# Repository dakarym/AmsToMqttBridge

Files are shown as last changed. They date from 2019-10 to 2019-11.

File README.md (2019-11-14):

# AMS <-> MQTT Bridge
 This project may help you build your own reader for HAN data streamed from the new AMS electrical meters installed in Norway in 2017/2018. Data is read using an Arduino-programmed ESP8266 (in an ESP12 module from AI Thinker), then pushed to MQTT over WiFi. You can have full control over this data, and you can basically do anything with it. 

 This project does not include any fancy UI setup or even storage for the AMS data.

 *Building this project will require some skills in ordering and assembling  electronic circuits as well as programming, and I have not included detailed instructions to take a beginner through the steps. I still hope some still find information here useful, maybe also for other projects.*

## Self powered HAN reader -- Work in progress

This is an update for a new self powered HAN [PCB](/PCB/KiCAD/HAN_SELF_POWERED) as originally conceived by ArnieO on the home automation [thread](https://www.hjemmeautomasjon.no/forums/topic/4933-lesing-av-amshan-uten-spenningsforsyning-the-complicated-way/).  Details on the hardware change is on the PCB [README](/PCB/README.md).  This version does not need a USB power connection.  Instead energy is taken from the HAN port connection and stored for use on the board.  A DC-DC buck converter based on the LTC3642 provides 3.3V at ~35ma from the 24V supply.  

The design has been tested and running successfully on an Aidon meter for the last 3 months.  Currently testing is pending on Kamstrup and Kafia style meters.

#### Open items / Limitations:
* The current that the buck can provide is limited to the maximum power supported by the meter HAN port.  The maximum value varies based on the meter type.  More information can be found [here](/Debugging/Documentation).  Currently the Aidon has the highest power available, but also has the fastest list frequency of 2.5 seconds.  Kamstrup and Kafia are at 10 second lists which may be beneficial as more time can be spent in low power idling.
* The most critical time for energy starvation is during the inital startup.  If the wifi or MQTT connection takes too long, the device will drop below the 2.65V cutoff for the voltage supervisor and will restart.  
* Due to this, the following edits in the [sketch](/Arduino Code/AmsToMqttBridge/AmsToMqttBridge.ino) were made:
  * Elimination of the 5 second waiting for AP time
  * Checking of the Vcc level at bootup and deepsleeping if insufficient voltage
  * Checking of the Vcc before entering the read message loop
* Fine tuning of the peak current trip threshold on the buck converter to balance average power draw with minimizing peak currents.
* Fine tuning of input current surge limiters for different meter types.  To be tested/verified soon.
  * Currently the design uses an NSI45020 as a 20 ma current clamp.  Below is a screenshot of the input surge with discharged input capacitors.  Yellow is the input current with 0.1V per ma scaling.  Cyan is input voltage.  Note the peak current clamped at ~27ma.
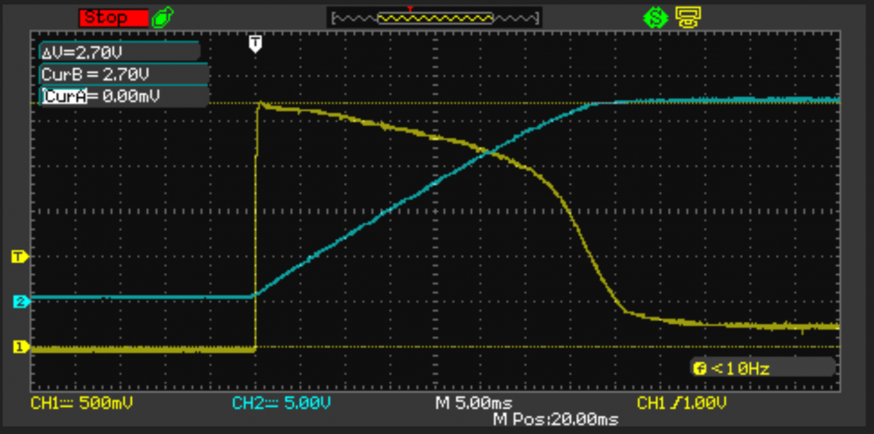
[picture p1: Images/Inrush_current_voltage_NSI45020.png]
NSI45020_Inrush

  * Alternatively an NPN current clamp could be used.  Such an example is shown below with the same measurements and scaling as above.  Note the peak current clamped at ~8.5ma.
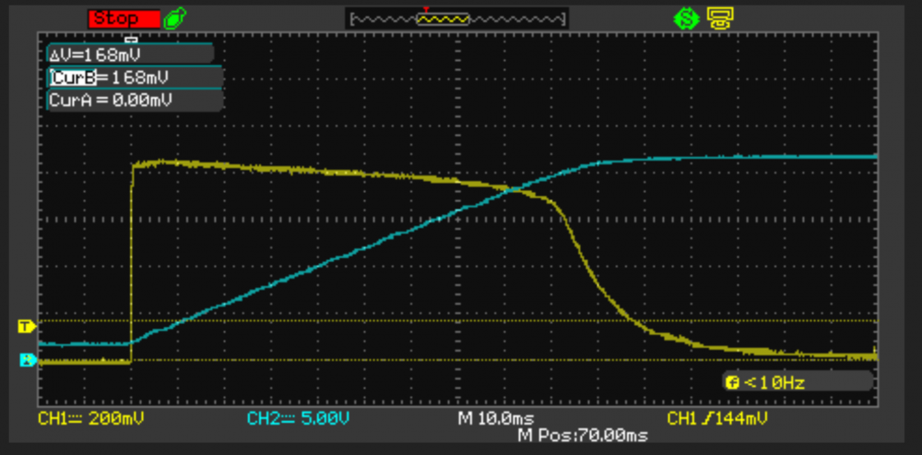
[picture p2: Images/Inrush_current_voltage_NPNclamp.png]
NPN_Inrush
  
* OTA updates will likely not be possible with this design, but will need testing
* Inital configuration of Wifi credentials and meter type will need to be done when connected to an external 3.3V supply.
* The auto reset funtionality  is implemented based on the circuit and testing of Kevin Darrah and explained [here](https://youtu.be/HdHzxM6fEig).  It is tested working on a couple of my boards with good results.

#### Next Steps:
* Test and verify on other meter types
* Respin PCB design to correct changes as needed
* Reduce cost of BOM and limited value components
* Share project on PCBWay
* Design optional case for 3d printing

## The previous hardware
The HAN Reader Hardware

*The completed board mounted in a [3D printed enclosure](/Electrical/HAN_ESP_TSS721/enclosure)*

The HAN Reader Installed

*...installed with the electrical meter...*

Data from MQTT displayed on a Node Red Dashboard

*...and, showing data on a [Node Red](https://nodered.org/) dashboard*

## Background
The purpose of this project is to collect information and build a simplified bridge for reading serial DLSM/M-bus information from electrical power meters (AMS), provided over the HAN port, and publishing to some IoT friendly target.

Components will be ESP8622, Arduino code and an M-bus <-> 3.3V serial interface

As a start, we should try to get information from the three types of AMS meters currently being installed in Norway. Some details about these are available here: [NVE_Info_kunder_HANgrensesnitt.pdf](./Debugging/Documentation/NVE_Info_kunder_HANgrensesnitt.pdf)

Quite some work was put into parse and guess how the data protocol was defined. Unfortunately, I did not have access to the (rather expensive) standardization documentation, but with some collaborative effort we solved most details.

### This project includes

- [X] [Circuit to read MBus data, parse the DSLM and report to MQTT over WiFi](./PCB/KiCAD/HAN_ESP_TSS721)
- [X] [Code to capture and analyze data from a PC](./Debugging/Code/HanDebugger)
- [X] [Code to capture and analyze data from Arduino](./Debugging/Code/ESPDebugger)
- [X] [Sample data from various meters](./Debugging/Samples)
- [X] [Documentation on HAN / MBus / DLMS/COSEM](./Debugging/Documentation)
- [X] [Code to parse DLMS data into a structure](./Arduino%20Code/Arduino%20Libraries/HanReader/src)
- [X] [Real schematics, including ESP8266](./PCB/KiCAD/HAN_ESP_TSS721#schematics)
- [X] [PCB layout](./PCB/KiCAD/HAN_ESP_TSS721#pcb)
- [X] [Component list](./PCB/KiCAD/HAN_ESP_TSS721#componenet-list)
- [X] [Arduino library](./Arduino%20Code)
- [X] [Complete Arduino sketch to read values and report to MQTT server](./Arduino%20Code/AmsToMqttBridge)

[The completed project](./Arduino%20Code/AmsToMqttBridge) also includes:

- Boot as Access Point and web server to allow config from a web browser. This allows you to set SSID, password, MQTT server and port, as well as topics for publish and subscribe
- On-board temperature sensor, also reported in json to MQTT

## Electrical design

The [most recent design](/PCB/KiCAD/HAN_ESP_TSS721) uses an [ESP8266](http://esp8266.net/) in an ESP12 module from [AI Thinker](https://www.ai-thinker.com) for micro processing and the [TSS721](http://www.ti.com/product/TSS721A) from Texas Instruments for level conversion from M-Bus to TTL (3.3V). An earlier design solved the level conversion using an op-amp, which might be an easier and more available solution, but also more error-prone. See more details in [electrical design](./Electrical).

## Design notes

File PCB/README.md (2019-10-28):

# Overview

Here are links to the different board designs together with a short summary.

## HAN_SELF_POWERED (Self contained and HAN Powered)

This [board](HAN_SELF_POWERED) contains a built in power supply to run without any external connection.  It is an evolution of the design proposed by ArnieO on the home automation forum [thread](https://www.hjemmeautomasjon.no/forums/topic/4933-lesing-av-amshan-uten-spenningsforsyning-the-complicated-way/).

Noteable changes from the below boards are:
* Uses [LTC3642](https://www.analog.com/media/en/technical-documentation/data-sheets/3642fc.pdf) for power delivery from the HAN signals
* Current limiter for preventing inrush tripping of overcurrent on HAN reader
* Voltage supervisor circuit via [TPS3808](http://www.ti.com/lit/ds/symlink/tps3808.pdf) for controlled ESP startup
* New layout with surface mount components and reduced size

Building notes:
* JP2 must be closed to enable recovery from deep sleep mode.  This is required.
* The EPS Prog/Reset circuitry is optional as the board can be programmed via the PROG and RST buttons.
* MRST button is optional, it forces a clean delay of the ESP reset.
* C7 is shown as a capacitor, but the latest version is a resistor value instead.  Next version will move to a resistor symbol.
* C6 can be omitted if desired.
* R1, R2 and R6 build custom hystersis for the TPS3808 based on [this](http://www.ti.com/lit/an/slva360/slva360.pdf) application note.

A (mostly) assembled prototype board is shown here:
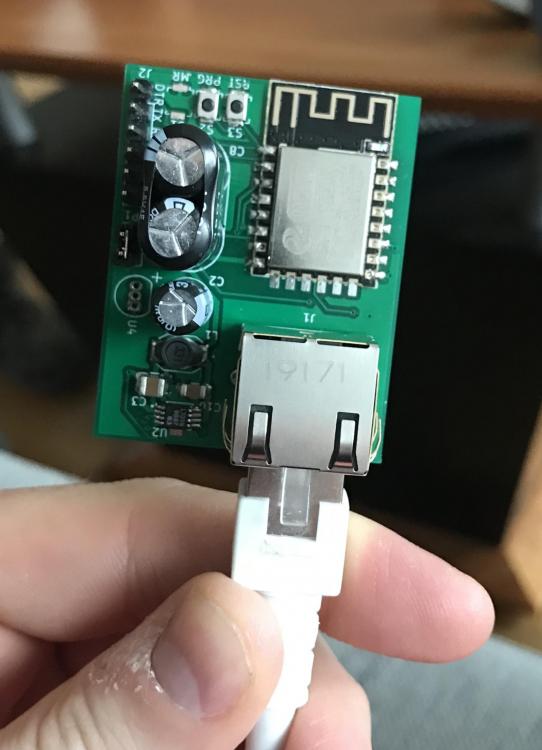
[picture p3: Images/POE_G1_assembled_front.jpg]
Board Front

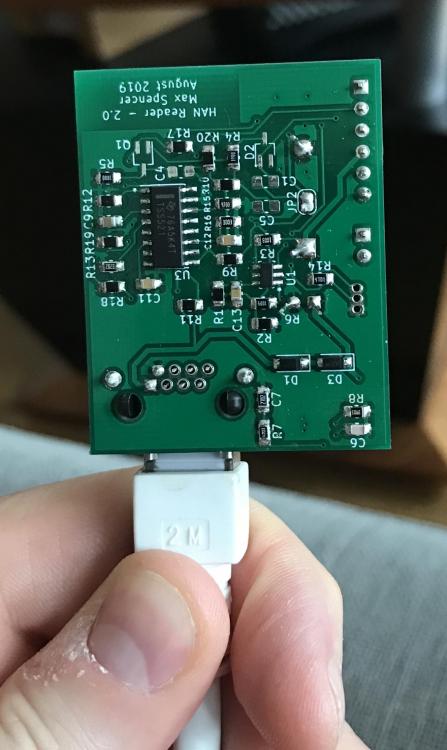
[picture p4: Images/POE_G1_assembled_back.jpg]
Board_Back


## HAN_ESP_TSS721 (USB Powered)

This is the current and most robust design for the [main board](HAN_ESP_TSS721). There's been great help in creating this, both here on GitHub, but also at the Norwegian home automation forum, [www.hjemmeautomasjon.no](https://www.hjemmeautomasjon.no/forums/topic/1982-lesing-av-ams-data-amshan-iot/)

The board

* uses TSS721 for MBus to TTL conversion
* holds ESP8266 for processing and transmit HAN data to WiFi / MQTT
* full schematics and PCB in editable [KiCad](http://www.kicad-pcb.org/) source files
* features a temperature sensor (DS18B20)
* uses a modular design, leaving these features optional
  * temperature sensor
  * M-bus TX
  * WiFi (Leave ESP, power supply and use for only M-bus to TTL)

### Status

At the time of this writing, this has never been tried as a whole, but all parts has been prototyped individually. First PCB prototypes are very soon in the order.

## HAN_ESP_Simple (Was: Board 1)

The project's original [board design](HAN_ESP_Simple). It

* is based on the ESP8266 chip
* is powered by USB
* uses a very simple voltage divider to demodulate the M-bus signal
* has shematic and pcb design only available as finished pdf/png files

### Status

Prototypes have been made and some people have started using them(?).

## HAN_TTL_TSS721 (Was: Board 2)

This [board design](HAN_TTL_TSS721) is a newer alternative to the original. It

* is an Arduino shield.
* uses the industry standard TSS721 chip to interface the M-bus.
* is optically isolate
* has shematic and pcb design available in editable [KiCad](http://www.kicad-pcb.org/) source files

### Status

Unfinished, just started.

## MBUS_Simulator (Was: Board 3)

This [board](MBUS_Simulator) is a M-bus master simulator to be able to develop and
test the other boards without being dependent on having and using a real AMS unit.

### Status

Implementation done.

Please also see [Getting started building or modifying](GETTING_STARTED.md)

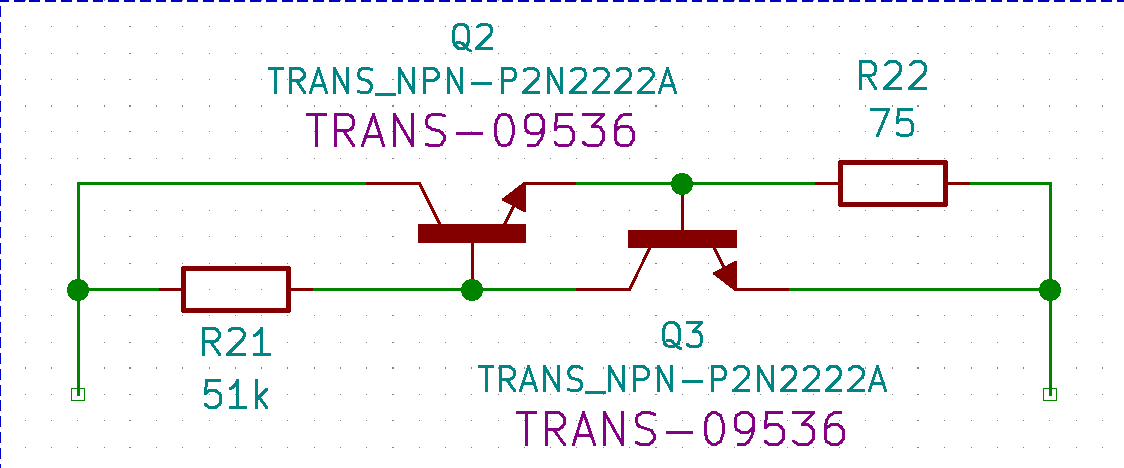
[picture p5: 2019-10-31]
PCB/KiCAD/HAN_SELF_POWERED/Capture.PNG

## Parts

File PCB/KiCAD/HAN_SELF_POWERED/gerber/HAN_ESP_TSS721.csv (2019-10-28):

Id | Designator | Package | Quantity | Designation | Supplier and ref
XX1 | C8 | DGH105Q5R5_17mm_8.5mm_12mmP | 1 | 1
XX2 | J2 | Pin_Header_Straight_1x06_Pitch2.54mm | 1 | FTDI
3 | U5 | ESP-12E_SMD | 1 | ESP-12E
XX4 | U2 | MSOP-8_MS | 1 | LTC3642IMS8EPBF
5 | U3 | SOIC-16_3.9x9.9mm_Pitch1.27mm | 1 | TSS721
XX6 | JP1 | Pin_Header_Straight_1x02_Pitch2.54mm | 1 | RX
XX7 | JP2 | SolderJumper-2_P1.3mm_Open_RoundedPad1.0x1.5mm | 1 | SolderJumper_2_Open
XX8 | R13 | R_0805_2012Metric_Pad1.15x1.40mm_HandSolder | 1 | 30k
9 | R15 | R_0805_2012Metric_Pad1.15x1.40mm_HandSolder | 1 | 470R
XX10 | R18,R17,R19,R20,R10,R9 | R_0805_2012Metric_Pad1.15x1.40mm_HandSolder | 6 | 10k
XX11 | R11,R12 | R_0805_2012Metric_Pad1.15x1.40mm_HandSolder | 2 | 220R
XX12 | R16,R3 | R_0805_2012Metric_Pad1.15x1.40mm_HandSolder | 2 | 100k
13 | R14 | R_0805_2012Metric_Pad1.15x1.40mm_HandSolder | 1 | 4k7
XX14 | R4,R5 | R_0805_2012Metric_Pad1.15x1.40mm_HandSolder | 2 | 100
XX15 | C2 | CP_Radial_D6.3mm_P2.50mm | 1 | 33u
XX16 | C3 | C_1210_3225Metric_Pad1.42x2.65mm_HandSolder | 1 | 10u
XX17 | C10 | C_1206_3216Metric_Pad1.42x1.75mm_HandSolder | 1 | 47u
XX18 | D2 | SOT-323_SC-70_Handsoldering | 1 | BAT54ADW
XX19 | D1 | D_SOD-123 | 1 | MBR130T1G
XX20 | D3 | D_SOD-123 | 1 | NSI45020
XX21 | Q1 | SOT-323_SC-70_Handsoldering | 1 | MMBT2907AWT1G
XX22 | R7,R6 | R_0805_2012Metric_Pad1.15x1.40mm_HandSolder | 2 | 1M
23 | R8 | R_0805_2012Metric_Pad1.15x1.40mm_HandSolder | 1 | 600k
XX24 | J1 | RJ45_Amphenol_RJHSE5380 | 1 | RJ45_Shielded
XX25 | C1,C4,C5 | C_0805_2012Metric_Pad1.15x1.40mm_HandSolder | 3 | 10u
26 | C6 | C_0805_2012Metric_Pad1.15x1.40mm_HandSolder | 1 | 1p
27 | C7 | C_0805_2012Metric_Pad1.15x1.40mm_HandSolder | 1 | 500n
XX28 | C11,C12 | C_0805_2012Metric_Pad1.15x1.40mm_HandSolder | 2 | 100n
XX29 | L1 | SRR6603-220ML | 1 | SRR6603-220ML
xx30 | R1 | R_0805_2012Metric_Pad1.15x1.40mm_HandSolder | 1 | 220k
XX31 | R2 | R_0805_2012Metric_Pad1.15x1.40mm_HandSolder | 1 | 33k
XX32 | S1,S2,S3 | Switch_Tactile_SMD_B3U-1000P | 3 | B3U-1000P
XX33 | U1 | SOT-23-6 | 1 | TPS3808G01DBVR
34 | U4 | TO-92_Inline | 1 | DS18B20
XX35 | C9 | C_0805_2012Metric_Pad1.15x1.40mm_HandSolder | 1 | 1u
XX36 | C13 | C_0805_2012Metric_Pad1.15x1.40mm_HandSolder | 1 | .1u

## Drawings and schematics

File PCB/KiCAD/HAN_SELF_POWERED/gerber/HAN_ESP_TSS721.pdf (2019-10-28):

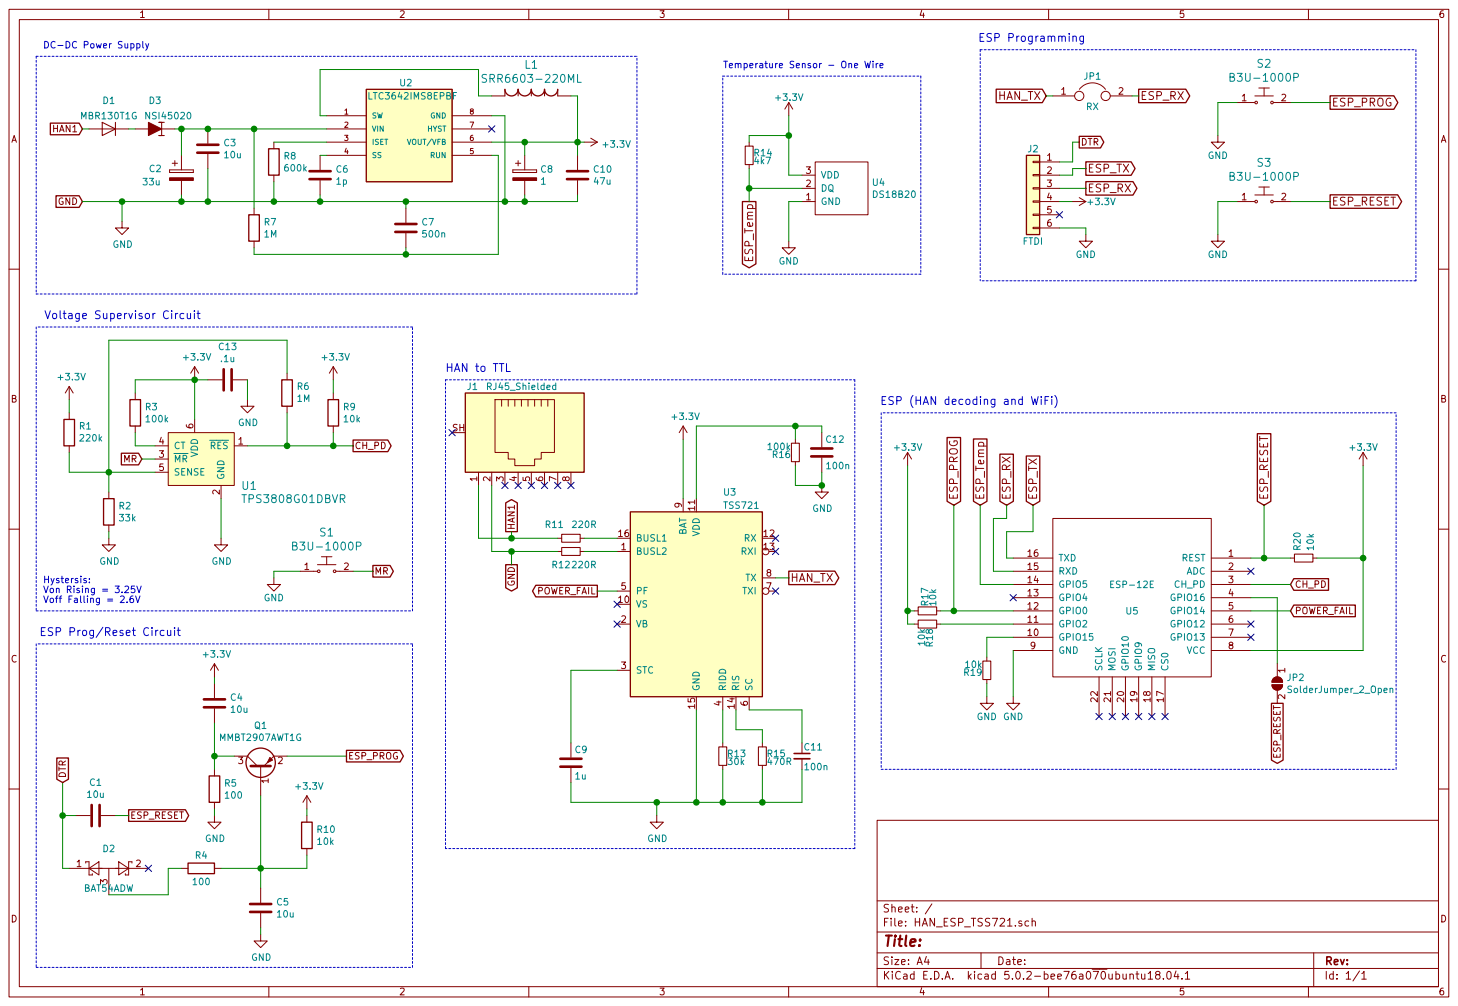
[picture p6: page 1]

Temperature Sensor - One Wire R14
+3.3V ESP_Temp

Voltage Supervisor Circuit+3.3V GND

2 MR 3 CT 4 SENSE 5 VDD

9 U3TSS721 REST 1 GPIO15 10 GPIO2 11 GPIO0 12 GPIO4 13 GPIO5 14 RXD 15 TXD 16 CS0 17 MISO 18 GPIO9 19 ADC 2 GPIO10 20 MOSI 21 SCLK 22 CH_PD 3 GPIO16 4 GPIO14 5 GPIO12 6 GPIO13 7 VCC 8 GND 9 U5 ESP-12E C9

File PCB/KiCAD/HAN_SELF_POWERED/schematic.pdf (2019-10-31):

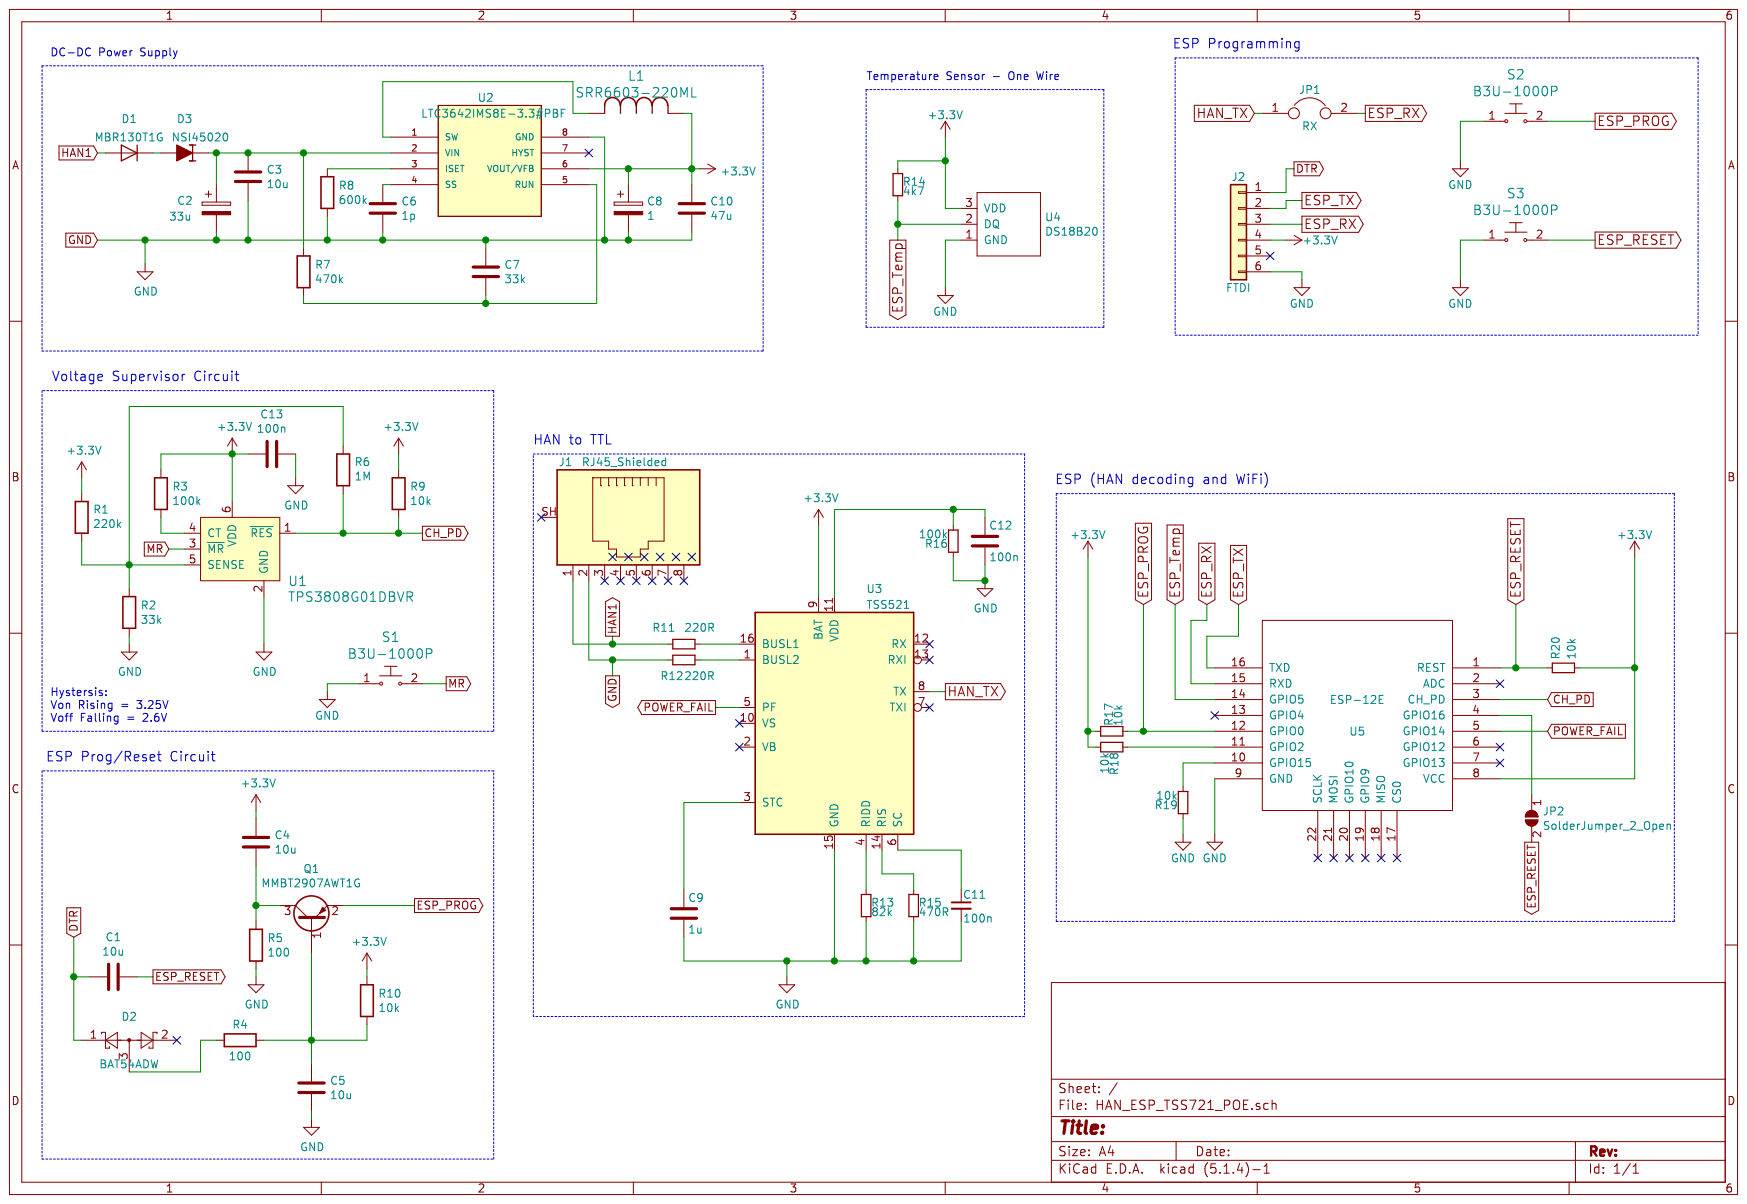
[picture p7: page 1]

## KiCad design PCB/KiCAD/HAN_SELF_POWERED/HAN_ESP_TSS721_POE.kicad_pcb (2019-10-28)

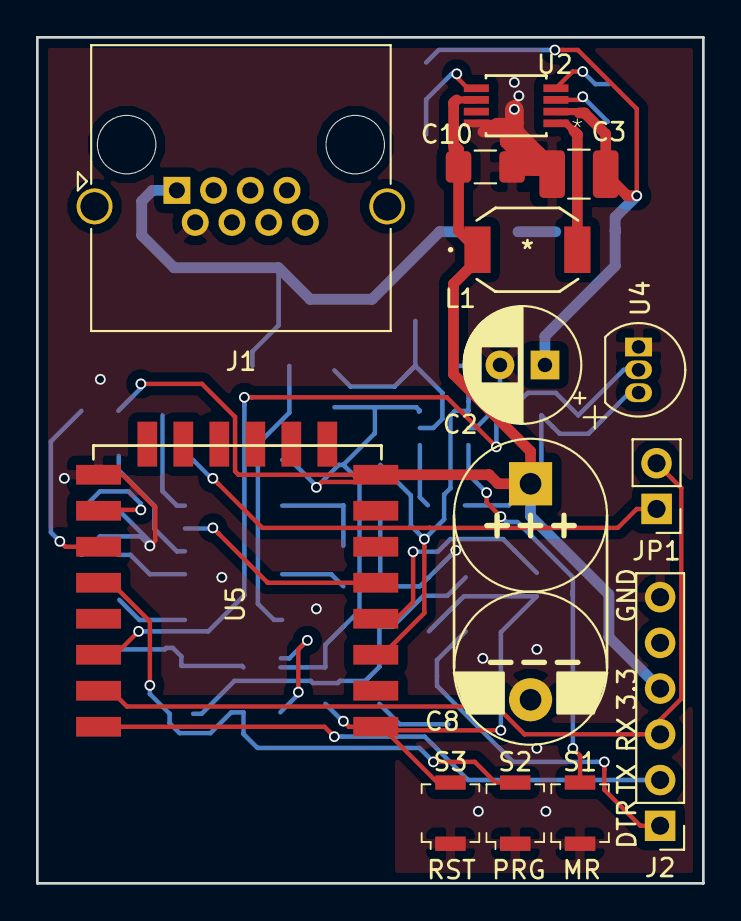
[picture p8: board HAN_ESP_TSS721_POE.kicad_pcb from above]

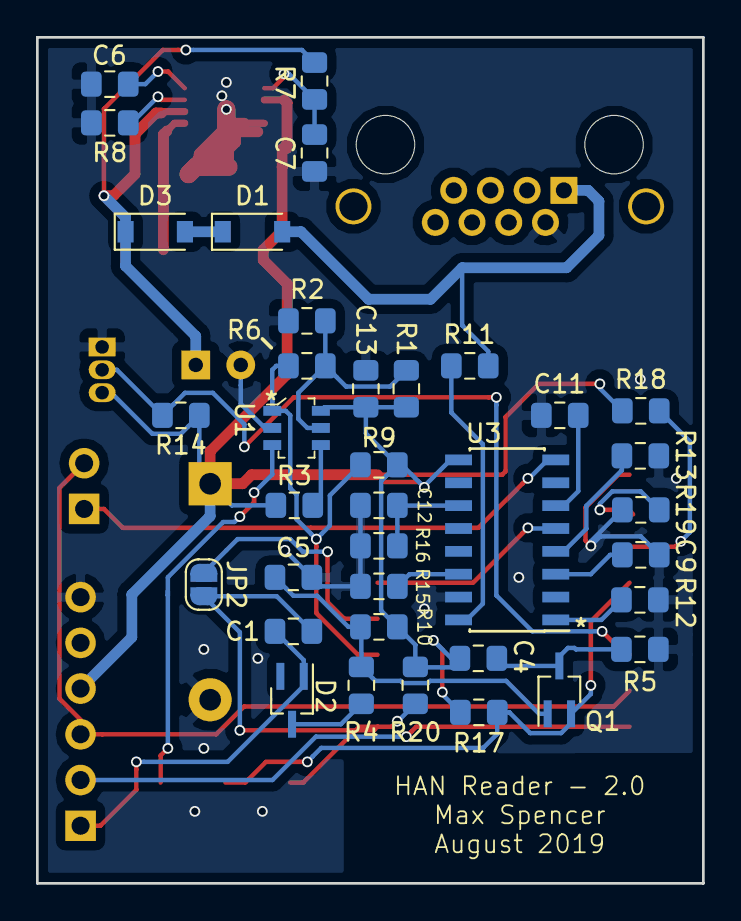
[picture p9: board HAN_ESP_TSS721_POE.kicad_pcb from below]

Board: 2 copper layers, 37.0 x 47.0 mm, 50 parts (36 on the bottom side), 34 nets.

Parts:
C1, C4, C5: 10u; C_0805_2012Metric_Pad1.15x1.40mm_HandSolder
C2: 33u; CP_Radial_D6.3mm_P2.50mm
C3: 10u; C_1210_3225Metric_Pad1.42x2.65mm_HandSolder
C6: 1p; C_0805_2012Metric_Pad1.15x1.40mm_HandSolder
C7: 500n; C_0805_2012Metric_Pad1.15x1.40mm_HandSolder
C8: 1; DGH105Q5R5_17mm_8.5mm_12mmP
C9: 1u; C_0805_2012Metric_Pad1.15x1.40mm_HandSolder
C10: 47u; C_1206_3216Metric_Pad1.42x1.75mm_HandSolder
C11, C12: 100n; C_0805_2012Metric_Pad1.15x1.40mm_HandSolder
C13: .1u; C_0805_2012Metric_Pad1.15x1.40mm_HandSolder
D1: MBR130T1G; D_SOD-123
D2: BAT54ADW; SOT-323_SC-70_Handsoldering
D3: NSI45020; D_SOD-123
J1: RJ45_Shielded; RJ45_Amphenol_RJHSE5380
J2: FTDI; Pin_Header_Straight_1x06_Pitch2.54mm
JP1: RX; Pin_Header_Straight_1x02_Pitch2.54mm
JP2: SolderJumper_2_Open; SolderJumper-2_P1.3mm_Open_RoundedPad1.0x1.5mm
L1: SRR6603-220ML
Q1: MMBT2907AWT1G; SOT-323_SC-70_Handsoldering
R1: 220k; R_0805_2012Metric_Pad1.15x1.40mm_HandSolder
R2: 33k; R_0805_2012Metric_Pad1.15x1.40mm_HandSolder
R3, R16: 100k; R_0805_2012Metric_Pad1.15x1.40mm_HandSolder
R4, R5: 100; R_0805_2012Metric_Pad1.15x1.40mm_HandSolder
R6, R7: 1M; R_0805_2012Metric_Pad1.15x1.40mm_HandSolder
R8: 600k; R_0805_2012Metric_Pad1.15x1.40mm_HandSolder
R9, R10, R17, R18, R19, R20: 10k; R_0805_2012Metric_Pad1.15x1.40mm_HandSolder
R11, R12: 220R; R_0805_2012Metric_Pad1.15x1.40mm_HandSolder
R13: 30k; R_0805_2012Metric_Pad1.15x1.40mm_HandSolder
R14: 4k7; R_0805_2012Metric_Pad1.15x1.40mm_HandSolder
R15: 470R; R_0805_2012Metric_Pad1.15x1.40mm_HandSolder
S1, S2, S3: B3U-1000P; Switch_Tactile_SMD_B3U-1000P
U1: TPS3808G01DBVR; SOT-23-6
U2: LTC3642IMS8EPBF; MSOP-8_MS
U3: TSS721; SOIC-16_3.9x9.9mm_Pitch1.27mm
U4: DS18B20; TO-92_Inline
U5: ESP-12E; ESP-12E_SMD

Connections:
+3V3: C4.1, C8.1, C10.1, C13.2, J2.4, L1.1, R1.2, R3.1, R9.1, R10.1, R14.1, R17.1, R18.2, R20.2, U1.6, U2.6, U3.9, U4.3, U5.8
CH_PD: R6.1, R9.2, U1.1, U5.3
DTR: C1.2, D2.1, J2.1
ESP_PROG: Q1.2, R17.2, S2.2, U5.12
ESP_RESET: C1.1, JP2.2, R20.1, S3.2, U5.1
ESP_RX: J2.3, JP1.2, U5.15
ESP_TX: J2.2, U5.16
ESP_Temp: R14.2, U4.2, U5.14
GND: C2.2, C3.2, C5.2, C6.2, C7.1, C8.2, C9.2, C10.2, C11.2, C12.2, C13.1, J1.2, J2.6, R2.2, R5.2, R8.2, R12.2, R13.2, R15.2, R16.1, R19.1, S1.1, S2.1, S3.1, U1.2, U2.8, U3.15, U4.1, U5.9
HAN1: D1.2, J1.1, R11.1
HAN_TX: JP1.1, U3.8
MR: S1.2, U1.3
unnamed: C2.1, C3.1, D3.1, R7.1, U2.2
unnamed: C4.2, Q1.3, R5.1
unnamed: C5.1, Q1.1, R4.1, R10.2
unnamed: C6.1, U2.4
unnamed: C7.2, R7.2, U2.5
unnamed: C9.1, U3.3
unnamed: C11.1, U3.6
unnamed: C12.1, R16.2, U3.11
unnamed: D1.1, D3.2
unnamed: D2.3, R4.2
unnamed: JP2.1, U5.4
unnamed: L1.2, U2.1
unnamed: R1.1, R2.1, R6.2, U1.5
unnamed: R3.2, U1.4
unnamed: R8.1, U2.3
unnamed: R11.2, U3.16
unnamed: R12.1, U3.1
unnamed: R13.1, U3.4
unnamed: R15.1, U3.14
unnamed: R18.1, U5.11
unnamed: R19.2, U5.10
POWER_FAIL: U3.5, U5.5

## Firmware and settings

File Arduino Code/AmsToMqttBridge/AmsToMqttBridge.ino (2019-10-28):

/*
 Name:		AmsToMqttBridge.ino
 Created:	3/13/2018 7:40:28 PM
 Author:	roarf
*/

ADC_MODE(ADC_VCC);    //Set the ADC to read VCC rather than external voltage, used for supply voltage monitoring

#define HAS_DALLAS_TEMP_SENSOR 1		// Set to zero if Dallas one wire temp sensor is not present
#define IS_CUSTOM_AMS_BOARD 0			// Set to zero if using NodeMCU or board not designed by Roar Fredriksen
#define IS_POE_AMS_BOARD 1        // Set to 1 for board with integrated power supply

#include <ArduinoJson.h>
#include <MQTT.h>

#if HAS_DALLAS_TEMP_SENSOR
#include <DallasTemperature.h>
#include <OneWire.h>
#endif

#if defined(ESP8266)
#include <ESP8266WiFi.h>
#elif defined(ESP32)
#include <WiFi.h>
#endif

#include "HanConfigAp.h"
#include "HanReader.h"
#include "HanToJson.h"

#define WIFI_CONNECTION_TIMEOUT 30000;

#if IS_CUSTOM_AMS_BOARD
#define LED_PIN 2 // The blue on-board LED of the ESP8266 custom AMS board
#define LED_ACTIVE_HIGH 0
#define AP_BUTTON_PIN 0
#elif IS_POE_AMS_BOARD
#define LED_PIN 2 // The blue on-board LED of the ESP8266 custom AMS board
#define LED_ACTIVE_HIGH 0
#define AP_BUTTON_PIN INVALID_BUTTON_PIN    //Set AP button as invalid to omit 5 second AP delay to limit power consumption
#else
#define LED_PIN LED_BUILTIN
#define LED_ACTIVE_HIGH 1
#define AP_BUTTON_PIN INVALID_BUTTON_PIN
#endif

#if HAS_DALLAS_TEMP_SENSOR
#define TEMP_SENSOR_PIN 5 // Temperature sensor connected to GPIO5

OneWire oneWire(TEMP_SENSOR_PIN);
DallasTemperature tempSensor(&oneWire);
#endif

// Object used to boot as Access Point
HanConfigAp ap;

// WiFi client and MQTT client
WiFiClient *client;
MQTTClient mqtt(384);

// Object used for debugging
HardwareSerial* debugger = NULL;

// The HAN Port reader, used to read serial data and decode DLMS
HanReader hanReader;

// the setup function runs once when you press reset or power the board
void setup()
{
	// Uncomment to debug over the same port as used for HAN communication
	//debugger = &Serial;

	if (debugger) {
		// Setup serial port for debugging
		debugger->begin(2400, SERIAL_8E1);
		//debugger->begin(115200);
		while (!debugger);
		debugger->println("");
		debugger->println("Started...");
    debugger->print(ESP.getVcc());
	}

  // Check Vcc to sense if voltage is high enough to boot without restart --> Vcc value may need to be tuned?
  if (ESP.getVcc() < 3450) {
    if (debugger) debugger->println("Voltage is too low");
    if (debugger) debugger->println(ESP.getVcc());
    ESP.deepSleep(5000000);    //Deep sleep for 5 seconds to allow output cap to charge up
  }  

	// Flash the LED, to indicate we can boot as AP now (skip if AP button is invalid)
  if (AP_BUTTON_PIN != INVALID_BUTTON_PIN) {
	pinMode(LED_PIN, OUTPUT);
	led_on();

	delay(1000);
  }

	// Initialize the AP
	ap.setup(AP_BUTTON_PIN, debugger);

	led_off();

	if (!ap.isActivated)
	{
		setupWiFi();
		// Configure uart for AMS data
		Serial.begin(2400, SERIAL_8E1);
		while (!Serial);

		hanReader.setup(&Serial, debugger);

		// Compensate for the known Kaifa bug
		hanReader.compensateFor09HeaderBug = (ap.config.meterType == 1);
	}
}

// the loop function runs over and over again until power down or reset
void loop()
{
	// Only do normal stuff if we're not booted as AP
	if (!ap.loop())
	{
		// Turn off the LED
		led_off();

		// allow the MQTT client some resources
		mqtt.loop();
		delay(10); // <- fixes some issues with WiFi stability

		// Reconnect to WiFi and MQTT as needed
		if (!mqtt.connected()) {
			MQTT_connect();
		}
		else
		{
			// Read data from the HAN port
			readHanPort();
		}
	}
	else
	{
		// Continously flash the LED when AP mode
		if (millis() / 1000 % 2 == 0)   led_on();
		else							led_off();
	}
}


void led_on()
{
#if LED_ACTIVE_HIGH
	digitalWrite(LED_PIN, HIGH);
#else
	digitalWrite(LED_PIN, LOW);
#endif
}


void led_off()
{
#if LED_ACTIVE_HIGH
	digitalWrite(LED_PIN, LOW);
#else
	digitalWrite(LED_PIN, HIGH);
#endif
}


void setupWiFi()
{
	// Turn off AP
	WiFi.enableAP(false);

	// Connect to WiFi
	WiFi.mode(WIFI_STA);
  WiFi.setOutputPower(0);
	WiFi.begin(ap.config.ssid, ap.config.ssidPassword);

	// Wait for WiFi connection
	if (debugger) debugger->print("\nWaiting for WiFi to connect...");
	while (WiFi.status() != WL_CONNECTED) {
		if (debugger) debugger->print(".");
		delay(500);
	}
	if (debugger) debugger->println(" connected");

	client = new WiFiClient();
	mqtt.begin(ap.config.mqtt, *client);

	// Direct incoming MQTT messages
	if (ap.config.mqttSubscribeTopic != 0 && strlen(ap.config.mqttSubscribeTopic) > 0) {
		mqtt.subscribe(ap.config.mqttSubscribeTopic);
		mqtt.onMessage(mqttMessageReceived);
	}

	// Notify everyone we're here!
	sendMqttData("Connected!");
}

void mqttMessageReceived(String &topic, String &payload)
{

	if (debugger) {
		debugger->println("Incoming MQTT message:");
		debugger->print("[");
		debugger->print(topic);
		debugger->print("] ");
		debugger->println(payload);
	}

	// Do whatever needed here...
	// Ideas could be to query for values or to initiate OTA firmware update
}

void readHanPort()
{
	if (hanReader.read() && ESP.getVcc() > 2800)    // Check that Vcc is okay before reading --> test is this is needed?  probably delete?
	{
		// Flash LED on, this shows us that data is received
		led_on();

		// Get the timestamp (as unix time) from the package
		time_t time = hanReader.getPackageTime();
		if (debugger) debugger->print("Time of the package is: ");
		if (debugger) debugger->println(time);

		// Define a json object to keep the data
		StaticJsonDocument<500> json;

		// Any generic useful info here
		json["id"] = WiFi.macAddress();
		json["up"] = millis();
		json["t"] = time;
    json["vcc"] = ESP.getVcc();

		// Add a sub-structure to the json object,
		// to keep the data from the meter itself
		JsonObject data = json.createNestedObject("data");

#if HAS_DALLAS_TEMP_SENSOR
		// Get the temperature too
		tempSensor.requestTemperatures();
		data["temp"] = tempSensor.getTempCByIndex(0);
#endif

		hanToJson(data, ap.config.meterType, hanReader);

		// Write the json to the debug port
		if (debugger) {
			debugger->print("Sending data to MQTT: ");
			serializeJsonPretty(json, *debugger);
			debugger->println();
		}

		// Make sure we have configured a publish topic
		if (! ap.config.mqttPublishTopic == 0 || strlen(ap.config.mqttPublishTopic) == 0)
		{
			// Publish the json to the MQTT server
			String msg;
			serializeJson(json, msg);

			mqtt.publish(ap.config.mqttPublishTopic, msg.c_str());
			mqtt.loop();
		}

		// Flash LED off
		led_off();
	}
}


// Function to connect and reconnect as necessary to the MQTT server.
// Should be called in the loop function and it will take care if connecting.
void MQTT_connect()
{
	// Connect to WiFi access point.
	if (debugger)
	{
		debugger->println();
		debugger->println();
		debugger->print("Connecting to WiFi network ");
		debugger->println(ap.config.ssid);
	}

	if (WiFi.status() != WL_CONNECTED)
	{
		// Make one first attempt at connect, this seems to considerably speed up the first connection
		WiFi.disconnect();
		WiFi.begin(ap.config.ssid, ap.config.ssidPassword);
		delay(1000);
	}

	// Wait for the WiFi connection to complete
	long vTimeout = millis() + WIFI_CONNECTION_TIMEOUT;
	while (WiFi.status() != WL_CONNECTED) {
		delay(50);
		if (debugger) debugger->print(".");

		// If we timed out, disconnect and try again
		if (vTimeout < millis())
		{
			if (debugger)
			{
				debugger->print("Timout during connect. WiFi status is: ");
				debugger->println(WiFi.status());
			}
			WiFi.disconnect();
			WiFi.begin(ap.config.ssid, ap.config.ssidPassword);
			vTimeout = millis() + WIFI_CONNECTION_TIMEOUT;
		}
		yield();
	}

	if (debugger) {
		debugger->println();
		debugger->println("WiFi connected");
		debugger->println("IP address: ");
		debugger->println(WiFi.localIP());
		debugger->print("\nconnecting to MQTT: ");
		debugger->print(ap.config.mqtt);
		debugger->print(", port: ");
		debugger->print(ap.config.mqttPort);
		debugger->println();
	}

	// Wait for the MQTT connection to complete
	while (!mqtt.connected()) {
		// Connect to a unsecure or secure MQTT server
		if ((ap.config.mqttUser == 0 && mqtt.connect(ap.config.mqttClientID)) ||
			(ap.config.mqttUser != 0 && mqtt.connect(ap.config.mqttClientID, ap.config.mqttUser, ap.config.mqttPass)))
		{
			if (debugger) debugger->println("\nSuccessfully connected to MQTT!");

			// Subscribe to the chosen MQTT topic, if set in configuration
			if (ap.config.mqttSubscribeTopic != 0 && strlen(ap.config.mqttSubscribeTopic) > 0)
			{
				mqtt.subscribe(ap.config.mqttSubscribeTopic);
				if (debugger) debugger->printf("  Subscribing to [%s]\r\n", ap.config.mqttSubscribeTopic);
			}
		}
		else
		{
			if (debugger)
			{
				debugger->print(".");
				debugger->print("failed, ");
				debugger->println(" trying again in 5 seconds");
			}

			// Wait 2 seconds before retrying
			mqtt.disconnect();

			delay(2000);
		}

		// Allow some resources for the WiFi connection
		yield();
		delay(2000);
	}
}

// Send a simple string embedded in json over MQTT
void sendMqttData(String data)
{
	// Make sure we have configured a publish topic
	if (ap.config.mqttPublishTopic == 0 || strlen(ap.config.mqttPublishTopic) == 0)
		return;

	// Make sure we're connected
	if (!client->connected() || !mqtt.connected()) {
		MQTT_connect();
	}

	// Build a json with the message in a "data" attribute
	StaticJsonDocument<500> json;
	json["id"] = WiFi.macAddress();
	json["up"] = millis();
	json["data"] = data;

	// Stringify the json
	String msg;
	serializeJson(json, msg);

	// Send the json over MQTT
	mqtt.publish(ap.config.mqttPublishTopic, msg.c_str());

	if (debugger) debugger->print("sendMqttData: ");
	if (debugger) debugger->println(data);
}

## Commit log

2019-10-28 Added original Kicad files for self powered board
    [HAN_ESP_TSS721-B.Cu.gbl, HAN_ESP_TSS721-B.Mask.gbs, HAN_ESP_TSS721-B.Paste.gbp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]
2019-10-28 Updates to schematic R7, C7, U2, C13, R13, U3
2019-10-28 Update README.md
    First notes on self powered PCB
2019-10-28 Update README.md
    Updated for self powered board option

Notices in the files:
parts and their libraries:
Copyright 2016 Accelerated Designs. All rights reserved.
